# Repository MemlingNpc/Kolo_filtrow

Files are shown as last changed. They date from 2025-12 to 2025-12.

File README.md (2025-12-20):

# System Sterowania Kołem Filtrów i Kamerą Naukową Thorlabs 

Oprogramowanie sterujące przeznaczone do automatyzacji akwizycji obrazów multispektralnych. System integruje sterowanie zmotoryzowanym kołem filtrów (opartym na mikrokontrolerze ESP32) z obsługą kamery naukowej firmy Thorlabs.

Projekt został zrealizowany w ramach pracy inżynierskiej.

## Główne funkcjonalności

* **Obsługa Kamery Thorlabs:** Pełna kontrola nad parametrami ekspozycji i wzmocnienia (Gain).
* **Wizualizacja na żywo:** Podgląd obrazu z dynamiczną normalizacją histogramu (Auto-Contrast), umożliwiający podgląd 16-bitowych danych na standardowym monitorze.
* **Sterowanie Kołem Filtrów:** Komunikacja z ESP32, obsługa 8 pozycji filtrów, inteligentny wybór najkrótszej ścieżki ruchu.
* **Zapis Danych:** Możliwość zapisu surowych danych w formacie **16-bit TIFF** (bezstratny) lub podglądu w **8-bit PNG/TIFF**.
* **Tryb Automatyczny:** Sekwencyjne wykonywanie zdjęć dla wszystkich filtrów z automatycznym doborem ekspozycji na podstawie kalibracji.
* **Dedykowana Kalibracja:** Osobne narzędzie do wyznaczania współczynników ekspozycji dla każdego filtra.

## Wymagania Sprzętowe

1.  **Komputer PC:** System Windows
2.  **Kamera:** Kompatybilna z Thorlabs TSI SDK (np. seria Zelux, CS165CU).
3.  **Koło Filtrów (Hardware):**
    * Mikrokontroler ESP32-WROOM.
    * Silnik krokowy ze sterownikiem (np. A4988).
    * Enkoder magnetyczny absolutny AS5600 (I2C).

## Wymagania Programowe

* Python 3.10+
* Biblioteki Python (wymienione w `requirements.txt`)
* **Thorlabs Scientific Imaging SDK** (należy pobrać ze strony producenta i zainstalować sterowniki).

## Instalacja

1.  **Sklonuj repozytorium:**
    ```bash
    git clone https://github.com/MemlingNpc/Kolo_filtrow.git
    cd twoj-projekt
    ```

2.  **Zainstaluj wymagane biblioteki:**
    ```bash
    pip install PySide6 opencv-python pyserial tifffile numpy
    ```

3.  **Skonfiguruj SDK Thorlabs:**
    * Zainstaluj oprogramowanie Thorlabs Windos SDK https://www.thorlabs.com/software_pages/ViewSoftwarePage.cfm?Code=ThorCam.
    * Upewnij się, że biblioteka `thorlabs_tsi_sdk` jest dostępna w Twoim środowisku Python.
    * Upewnij się, że pliki DLL są w ścieżce systemowej (PATH) lub użyj skryptu `windows_setup.py`.

## Struktura Projektu

* `main_app.py` - Główna aplikacja sterująca (GUI, PySide6).
* `workers.py` - Logika wielowątkowa (obsługa kamery i portu szeregowego).
* `calibration.py` - Narzędzie do kalibracji filtrów (Tkinter).
* `config.json` - Plik konfiguracyjny generowany przez kalibrator.
* `windows_setup.py` - Skrypt pomocniczy do ładowania DLL Thorlabs.
* `stepper.ino` - Kod źródłowy dla mikrokontrolera ESP32 (Arduino C++).

## Modele 3D
* `kolozgwintami.stl` - Tarcza koła filtrów.
* `srubka.stl` - Śruba łącząca wał silnika z kołem.
* `srubkanamagnes.stl` - Śruba z mocowaniem na magnes.
* `ramka.stl` - Rama mocująca.
* `obudowa.stl` - Przednia część obudowy.
* `obudowa2.stl` - Tylna część obudowy.
* `pokrywkaduza.stl` - Pokrywa na elektronikę.
* `pokrywkamala.stl` - Pokrywa na enkoder.

## Konfiguracja i Kalibracja

Przed rozpoczęciem pracy zaleca się przeprowadzenie kalibracji:

1.  Uruchom `calibration.py`.
2.  Dla każdego filtra wczytaj zdjęcie wzorca bieli (Flat Field).
3.  Wybierz filtr referencyjny.
4.  Kliknij "Zapisz Konfigurację" – wygeneruje to plik `config.json`.

Plik `config.json` zawiera mapowanie pozycji filtrów oraz mnożniki czasów ekspozycji.

## Uruchomienie

1.  Podłącz ESP32 oraz kamerę do portów USB.
2.  Sprawdź w Menedżerze Urządzeń numer portu COM dla ESP32 (np. COM3).
3.  Edytuj `main_app.py` (linia `self.serial_port = "COM3"`), jeśli port jest inny.
4.  Uruchom aplikację:
    ```bash
    python main_app.py
    ```

## Autorzy

**Bartosz Twardowski, Jan Landecki**
Praca Inżynierska
Politechnika Gdańska
2025

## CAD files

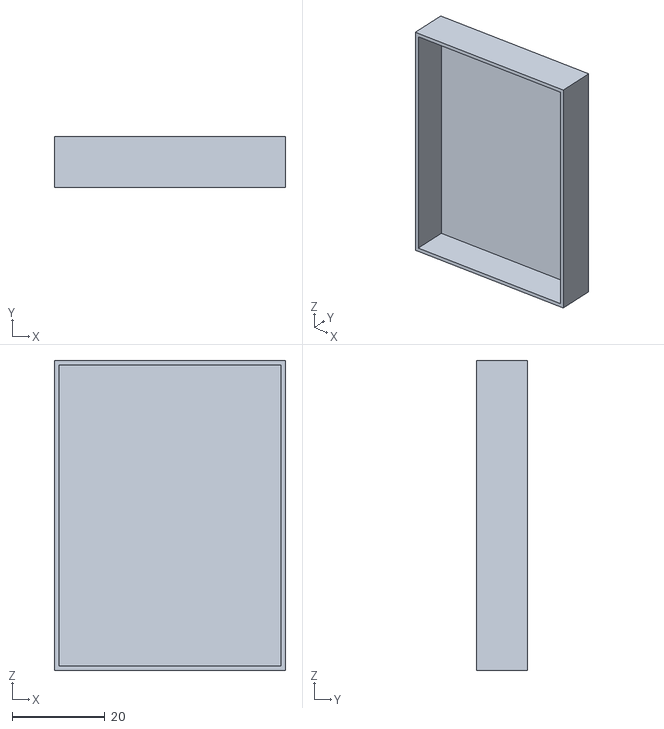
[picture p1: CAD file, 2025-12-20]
pokrywkamala.stl
50.0 x 11.0 x 67.0

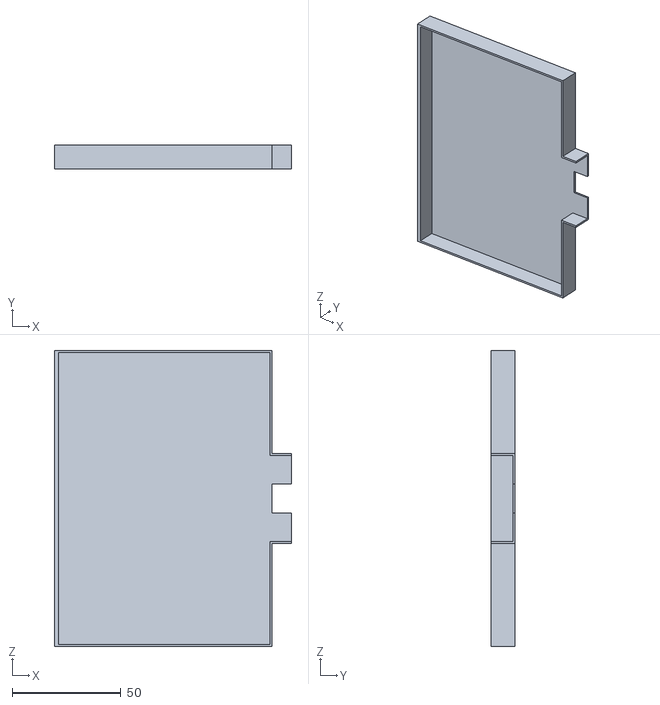
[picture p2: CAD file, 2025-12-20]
pokrywkaduza.stl
109.0 x 11.0 x 136.0

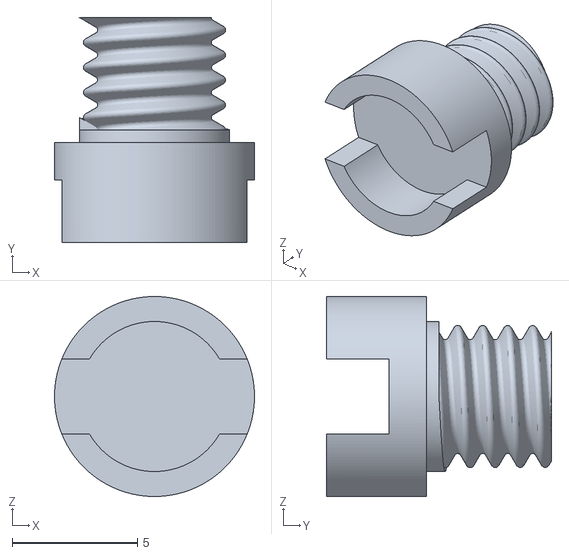
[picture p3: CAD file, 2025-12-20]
srubkanamagnes.stl
8.00 x 9.00 x 8.00

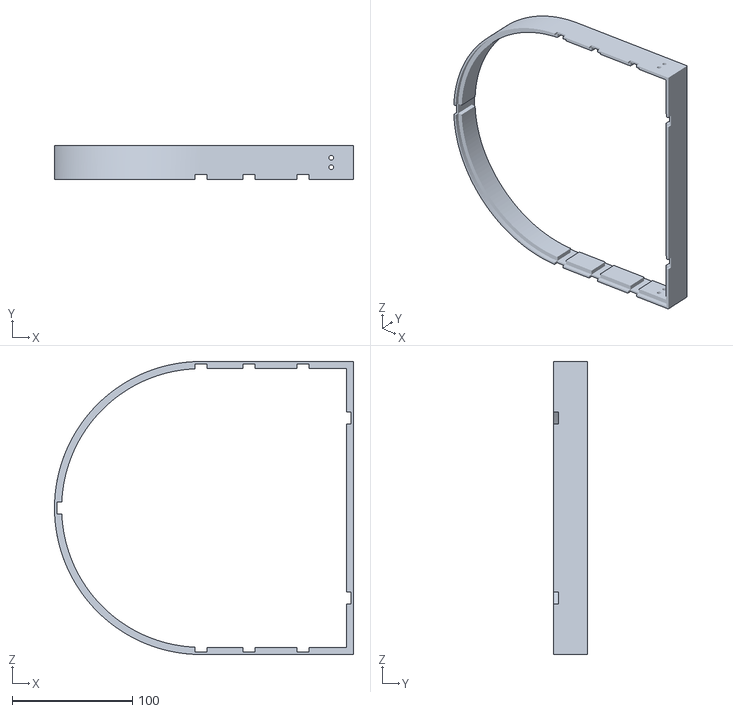
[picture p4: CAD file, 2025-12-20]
ramka.stl
249.0 x 28.0 x 244.0

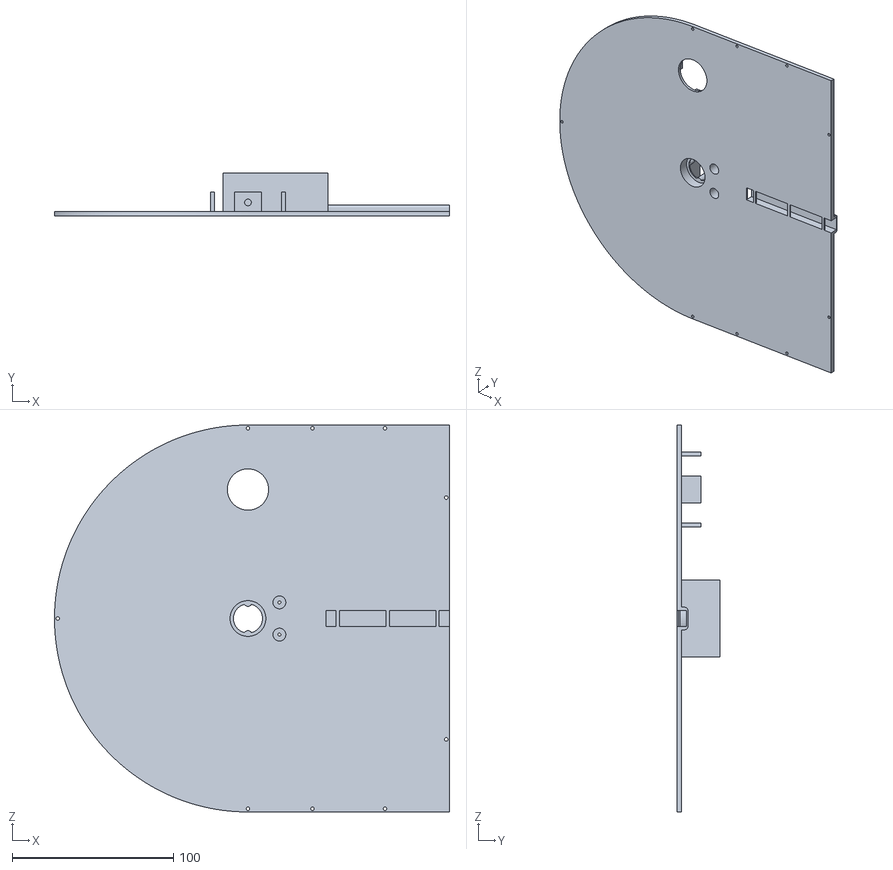
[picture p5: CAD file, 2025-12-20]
obudowa.stl
245.0 x 26.9 x 240.0

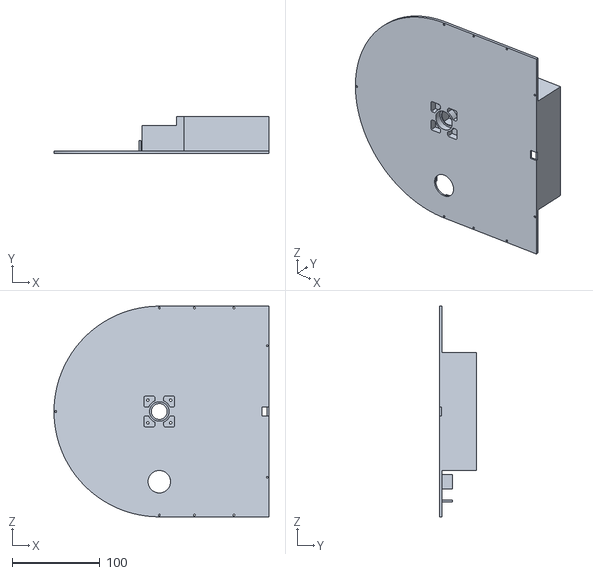
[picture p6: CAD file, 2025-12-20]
obudowa2.stl
245.0 x 41.9 x 240.0

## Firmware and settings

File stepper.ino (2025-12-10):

#include <AccelStepper.h>
#include <Wire.h>
#include "AS5600.h"
#define MOTOR_INTERFACE_TYPE 1
#define DIR_PIN 2
#define STEP_PIN 4
#define CTRLA_PIN 18
#define CTRLB_PIN 19
const int STEPS_PER_REVOLUTION = 200;
const int FILTER_COUNT = 8;
const long STEPS_PER_FILTER = STEPS_PER_REVOLUTION / FILTER_COUNT;
const int ENCODER_HOME_POSITION = 510;
const int ENCODER_STEPS_PER_FILTER = 512;
const int ENCODER_TOLERANCE = 15;
const int ENCODER_RANGE = 4096;
const int ENCODER_MID_RANGE = ENCODER_RANGE / 2;
const float HOMING_SPEED = 500;
const float CORRECTION_SPEED = 500;
int currentFilterPosition = 1;
String incomingCommand = ""; 

AccelStepper stepper(MOTOR_INTERFACE_TYPE, STEP_PIN, DIR_PIN);
AS5600 as5600; 
void setup() {
  Serial.begin(115200);
  Wire.begin(32, 33);
  as5600.begin(); 
  pinMode(CTRLA_PIN, OUTPUT);
  pinMode(CTRLB_PIN, OUTPUT);
  digitalWrite(CTRLA_PIN, LOW);
  digitalWrite(CTRLB_PIN, LOW);
  stepper.setMaxSpeed(6000);  
  stepper.setAcceleration(4000); 
  runHomingSequence();
}

void runHomingSequence() {
  stepper.setSpeed(HOMING_SPEED);
  while (true) {
    int currentAngle = as5600.readAngle();
    float degrees = currentAngle * (360.0 / 4095.0);
    Serial.print("Surowy kąt (0-4095): ");
    Serial.print(currentAngle);
    Serial.print("\t Kąt (stopnie): ");
    Serial.println(degrees, 2);
    int error = ENCODER_HOME_POSITION - currentAngle;
    if (error > ENCODER_MID_RANGE) {
      error -= ENCODER_RANGE;
    } else if (error < -ENCODER_MID_RANGE) {
      error += ENCODER_RANGE;
    }
    if (abs(error) <= ENCODER_TOLERANCE) {
      break; 
    }
    if (error > 0) {
      stepper.move(1);
    } else {
      stepper.move(-1);
    }
    stepper.runSpeed();
  }
  stepper.setCurrentPosition(0);
  currentFilterPosition = 1;
}
void loop() {
  checkSerialCommands();
}
void checkSerialCommands() {
  if (Serial.available() > 0) {
    incomingCommand = Serial.readStringUntil('\n');
    incomingCommand.trim();
    parseCommand(incomingCommand);
  }
}
void parseCommand(String command) {
  if (command.startsWith("GOTO:")) {
    String filterIdString = command.substring(5);
    int targetFilter = filterIdString.toInt();
    if (targetFilter >= 1 && targetFilter <= FILTER_COUNT) {
      unsigned long startTime = millis();
      moveFilter(targetFilter, startTime);
    } else {
      Serial.println("ERROR: Invalid filter ID (musi być 1-8)");
    }
  } else {
    Serial.println("ERROR: Unknown command");
  }
}
void moveFilter(int targetFilter, unsigned long startTime) {
  if (targetFilter == currentFilterPosition) {
    unsigned long endTime = millis();
    unsigned long duration = endTime - startTime;
    Serial.println("INFO: Czas zmiany: " + String(duration) + " ms (juz na miejscu)");
    Serial.println("OK:" + String(targetFilter));
    return;
  }

  long targetSteps = (long)(targetFilter - 1) * STEPS_PER_FILTER;

  int targetEncoderPosition = ENCODER_HOME_POSITION + (targetFilter - 1) * ENCODER_STEPS_PER_FILTER;

  stepper.moveTo(targetSteps);
  stepper.runToPosition();
  stepper.setSpeed(CORRECTION_SPEED);
  while (true) {

    int currentAngle = as5600.readAngle();
    float degrees = currentAngle * (360.0 / 4095.0);
    Serial.print("Surowy kąt (0-4095): ");
  Serial.print(currentAngle);
  Serial.print("\t Kąt (stopnie): ");
  Serial.println(degrees, 2);

    int error = targetEncoderPosition - currentAngle;

    if (error > ENCODER_MID_RANGE) {
      error -= ENCODER_RANGE;
    } else if (error < -ENCODER_MID_RANGE) {
      error += ENCODER_RANGE;
    }

    if (abs(error) <= ENCODER_TOLERANCE) {
      break; 
    }

    if (error > 0) {
      stepper.move(1);
    } else {
      stepper.move(-1);
    }

    stepper.runSpeed();
  }
  stepper.setCurrentPosition(targetSteps);
  unsigned long endTime = millis();
  unsigned long duration = endTime - startTime;

  Serial.println("INFO: Czas zmiany: " + String(duration) + " ms");

  currentFilterPosition = targetFilter;
  Serial.println("OK:" + String(currentFilterPosition));
}

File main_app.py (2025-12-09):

import sys
import json
import time
import os
import numpy as np
import cv2
import tifffile

from PySide6.QtWidgets import (
    QApplication, QMainWindow, QWidget,
    QVBoxLayout, QHBoxLayout, QPushButton,
    QGridLayout, QLabel, QDoubleSpinBox, QGroupBox,
    QMessageBox, QFileDialog, QComboBox
)
from PySide6.QtGui import QPixmap, QImage, QFont
from PySide6.QtCore import Qt, Slot, QThread, QThreadPool, QTimer

# Import tylko prawdziwych klas obsługi sprzętu
from workers import RealCameraService, RealSerialWorker


class FilterWheelApp(QMainWindow):
    def __init__(self):
        super().__init__()

        # --- Konfiguracja i zmienne ---
        self.filter_config = {}
        self.current_filter_pos = 0
        self.current_science_frame = None  # Przechowuje surowe dane 16-bit

        self.load_config()

        # Zmienne dla Trybu Automatycznego
        self.auto_mode_active = False
        self.auto_mode_steps = []
        self.auto_mode_current_step = 0

        self.setWindowTitle("Sterownik Koła Filtrów i Kamery Thorlabs (16-bit TIFF)")
        self.setGeometry(100, 100, 1100, 750)

        # Inicjalizacja wątków
        self.thread_pool = QThreadPool()
        self.camera_thread = QThread()
        self.camera_worker = None

        self.is_filter_wheel_busy = False
        self.serial_port = "COM3"
        self.serial_baud = 115200

        # --- Budowa Interfejsu (GUI) ---
        main_widget = QWidget()
        main_layout = QHBoxLayout()
        main_widget.setLayout(main_layout)
        self.setCentralWidget(main_widget)

        # 1. Kolumna Lewa (Podgląd i Zapis)
        left_column_layout = QVBoxLayout()

        self.image_label = QLabel("Łączenie z kamerą...")
        self.image_label.setFont(QFont("Arial", 16))
        self.image_label.setAlignment(Qt.AlignmentFlag.AlignCenter)
        self.image_label.setStyleSheet("border: 1px solid gray; background-color: #000;")
        self.image_label.setMinimumSize(640, 480)
        left_column_layout.addWidget(self.image_label, stretch=1)

        self.save_image_button = QPushButton("Zapisz obraz (TIFF)")
        self.save_image_button.setMinimumHeight(40)
        self.save_image_button.clicked.connect(self.prompt_for_save_image)
        left_column_layout.addWidget(self.save_image_button)

        main_layout.addLayout(left_column_layout, stretch=1)

        # 2. Kolumna Prawa (Sterowanie)
        right_column_layout = QVBoxLayout()

        # --- Panel Kamery ---
        camera_group_box = QGroupBox("Kontrola Kamery")
        camera_layout = QVBoxLayout()

        # Ekspozycja Bazowa
        base_exp_layout = QHBoxLayout()
        base_exp_label = QLabel("Ekspozycja Bazowa (ms):")
        self.base_exposure_spinbox = QDoubleSpinBox()
        self.base_exposure_spinbox.setRange(0.1, 10000.0)
        self.base_exposure_spinbox.setValue(10.0)
        self.base_exposure_spinbox.setSuffix(" ms")
        self.base_exposure_spinbox.valueChanged.connect(self.recalculate_current_exposure)
        base_exp_layout.addWidget(base_exp_label)
        base_exp_layout.addWidget(self.base_exposure_spinbox)
        camera_layout.addLayout(base_exp_layout)

        # Ekspozycja Aktualna (Wynikowa)
        exposure_layout = QHBoxLayout()
        exposure_label = QLabel("Aktualna Eksp. (Wynik):")
        self.exposure_spinbox = QDoubleSpinBox()
        self.exposure_spinbox.setRange(0.1, 60000.0)
        self.exposure_spinbox.setValue(10.0)
        self.exposure_spinbox.setSuffix(" ms")
        exposure_layout.addWidget(exposure_label)
        exposure_layout.addWidget(self.exposure_spinbox)
        camera_layout.addLayout(exposure_layout)

        # Wzmocnienie (Gain)
        gain_layout = QHBoxLayout()
        gain_label = QLabel("Gain (dB):")
        self.gain_spinbox = QDoubleSpinBox()
        self.gain_spinbox.setRange(0.0, 48.0)
        self.gain_spinbox.setValue(0.0)
        self.gain_spinbox.setSingleStep(0.1)
        self.gain_spinbox.setSuffix(" dB")
        gain_layout.addWidget(gain_label)
        gain_layout.addWidget(self.gain_spinbox)
        camera_layout.addLayout(gain_layout)

        # Przycisk Trybu Auto
        self.auto_mode_button = QPushButton("Uruchom Tryb Automatyczny")
        self.auto_mode_button.setMinimumHeight(40)
        self.auto_mode_button.setCheckable(True)
        self.auto_mode_button.clicked.connect(self.toggle_auto_mode)
        camera_layout.addWidget(self.auto_mode_button)

        # Wybór formatu zapisu
        format_layout = QHBoxLayout()
        format_label = QLabel("Format zapisu:")
        self.save_format_combo = QComboBox()
        self.save_format_combo.addItems(["TIFF 16-bit", "PNG 8-bit", "TIFF 8-bit"])
        format_layout.addWidget(format_label)
        format_layout.addWidget(self.save_format_combo)
        camera_layout.addLayout(format_layout)

        camera_group_box.setLayout(camera_layout)

        # --- Panel Koła Filtrów ---
        filter_group_box = QGroupBox("Kontrola Koła Filtrów")
        filter_layout = QGridLayout()
        self.filter_buttons = []
        positions_grid = [(i, j) for i in range(4) for j in range(2)]

        # Generowanie przycisków na podstawie configu
        for i in range(1, 9):
            config_data = self.filter_config.get(i, {})
            button_name = config_data.get('name', f'Filtr {i}')
            button = QPushButton(button_name)
            button.setMinimumHeight(40)
            button.clicked.connect(lambda checked=False, num=i: self.request_filter_change(num))
            self.filter_buttons.append(button)
            pos = positions_grid[i - 1]
            filter_layout.addWidget(button, pos[0], pos[1])

        # Nawigacja Poprzedni/Następny
        nav_layout = QHBoxLayout()
        self.prev_filter_button = QPushButton("Poprzedni")
        self.prev_filter_button.clicked.connect(self.request_prev_filter)
        self.next_filter_button = QPushButton("Następny")
        self.next_filter_button.clicked.connect(self.request_next_filter)
        nav_layout.addWidget(self.prev_filter_button)
        nav_layout.addWidget(self.next_filter_button)

        main_filter_layout = QVBoxLayout()
        main_filter_layout.addLayout(filter_layout)
        main_filter_layout.addLayout(nav_layout)
        filter_group_box.setLayout(main_filter_layout)

        # --- Panel Statusu ---
        status_group_box = QGroupBox("Status Systemu")
        status_layout = QVBoxLayout()
        self.status_camera_label = QLabel("Kamera: 🟡 Inicjalizacja...")
        self.status_filter_label = QLabel("Koło filtrów: ⚪ Oczekuje")
        self.status_current_filter_label = QLabel("Aktualny filtr: ?")
        self.status_auto_mode_label = QLabel("Tryb Auto: ⚪ Nieaktywny")
        self.status_auto_mode_label.setStyleSheet("font-weight: bold;")
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

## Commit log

2025-12-10 Correct error adjustment in encoder logic
    Fix error adjustment logic for encoder range.
    [stepper.ino]
2025-12-20 Add 3D models for filter wheel components
    Added 3D models related to the filter wheel system.
